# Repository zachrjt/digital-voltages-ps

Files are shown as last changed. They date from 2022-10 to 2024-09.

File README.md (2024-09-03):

# **Dual Fixed-Voltage Power Supply with V,I Readout**
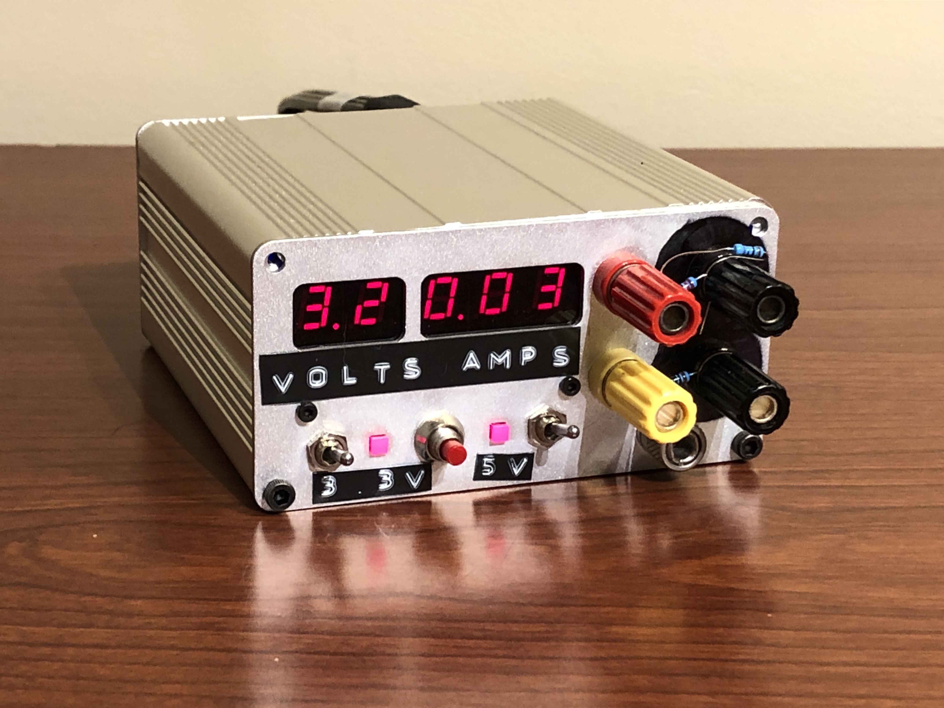
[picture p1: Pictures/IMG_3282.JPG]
Complete PS

## Background
The motivation behind this project was that in the past I have come across a need for a portable fixed-voltage 3.3V and 5V supplies. Specifically, I needed a supply that didn’t require me to set up a variable lab power supply while also being portable and rugged so that I could take it on the go.
Why did it end up taking on this *”polished”* look? I was looking to gain more SMD soldering experience and further my experience in PCB layout and schematic documentation. So, I approached this project in a more methodical, thorough-engineering manner than what I do typically for other personal projects of mine.
## Design and Construction
The main and display PCBs were captured and routed in KiCad, while the back and front enclosure panels were designed in Fusion 360. The code was, and is, written using the Arduino IDE and framework thanks only to the existence of the megaTinyCore library for 2-series attiny chips.
## Result
As seen in the picture above, the resulting power supply is certainly an *aesthetic*, but it is functional which is the most important thing. It took two PCB revisions of the main board because of wrong footprints for two resistors, and ~1 month of daily effort. There were many hours spent at my bench with an oscilloscope debugging my own oversights in the first PCB revision but I enjoyed every minute. The approach I took paid off since I've gained a lot of knowledge and experience where I wanted to, and the result is something I'm proud to share.

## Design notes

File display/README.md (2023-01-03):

# Display Board Schematic, PCB, and Documentation

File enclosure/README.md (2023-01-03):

# Back and Front Enclosure Panel CAD Files and Drawings

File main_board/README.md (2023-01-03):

# Main Board Schematic, PCB, and Documentation

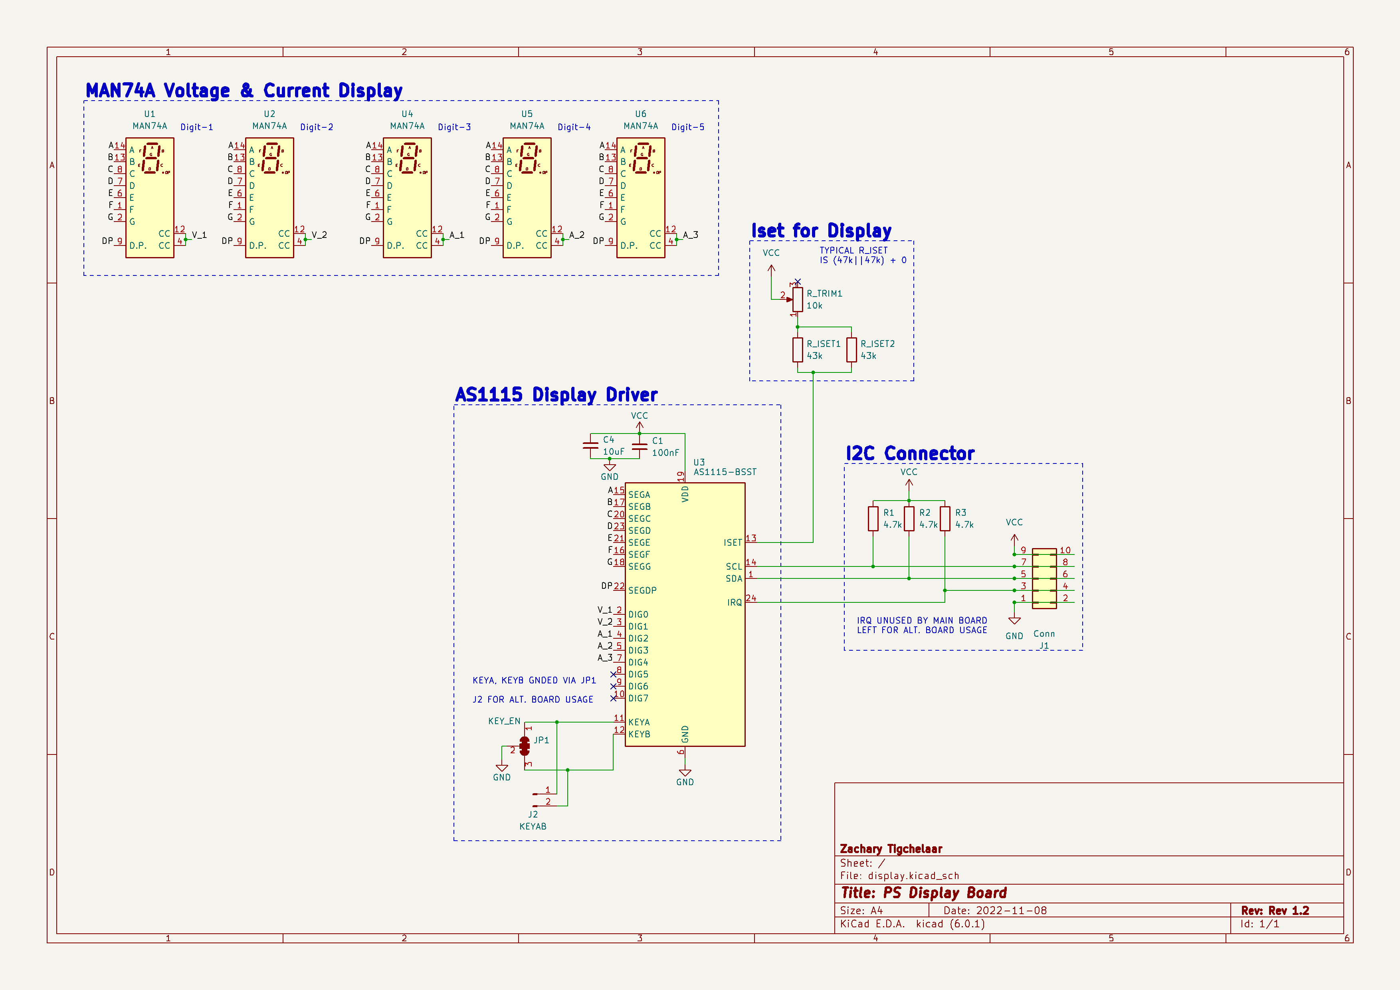
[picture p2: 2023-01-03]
display/display_board_schematic.png

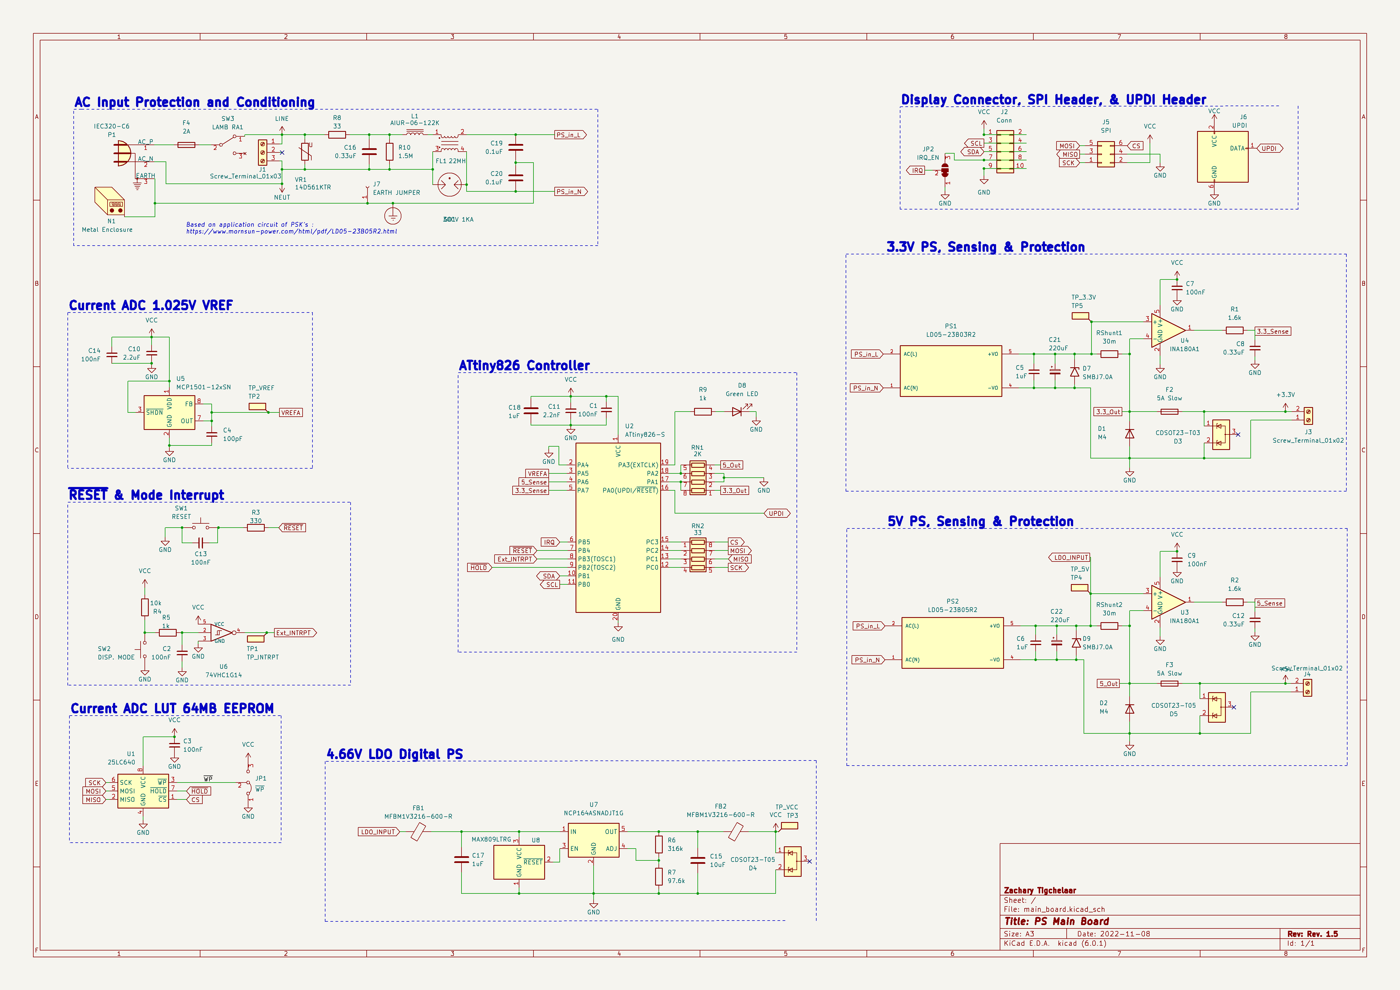
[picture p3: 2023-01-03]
main_board/main_board_schematic.png

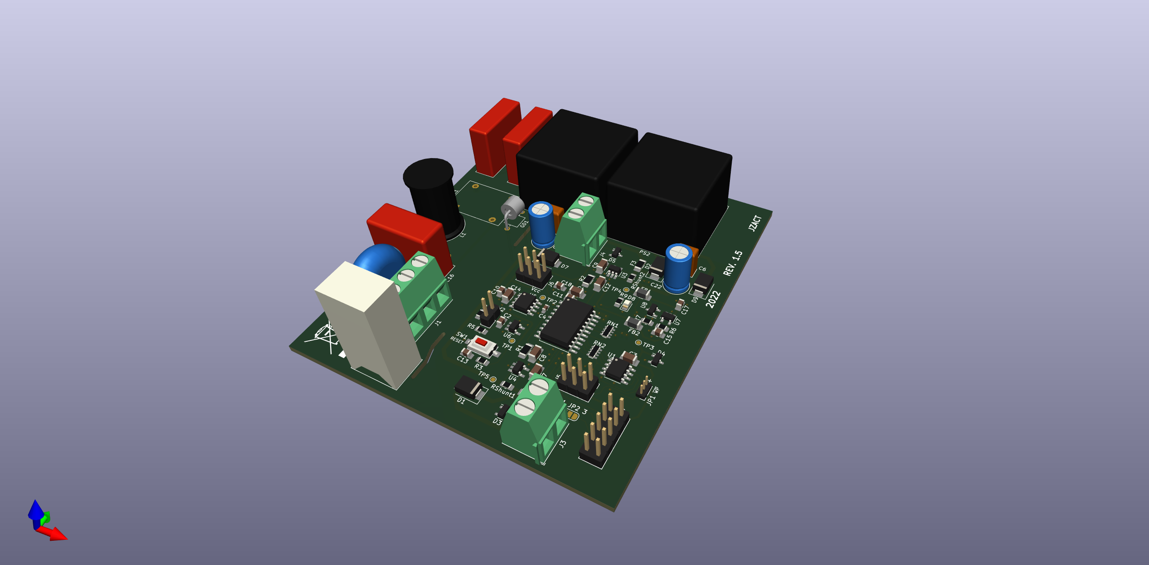
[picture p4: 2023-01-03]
main_board/main_board_iso_view.png

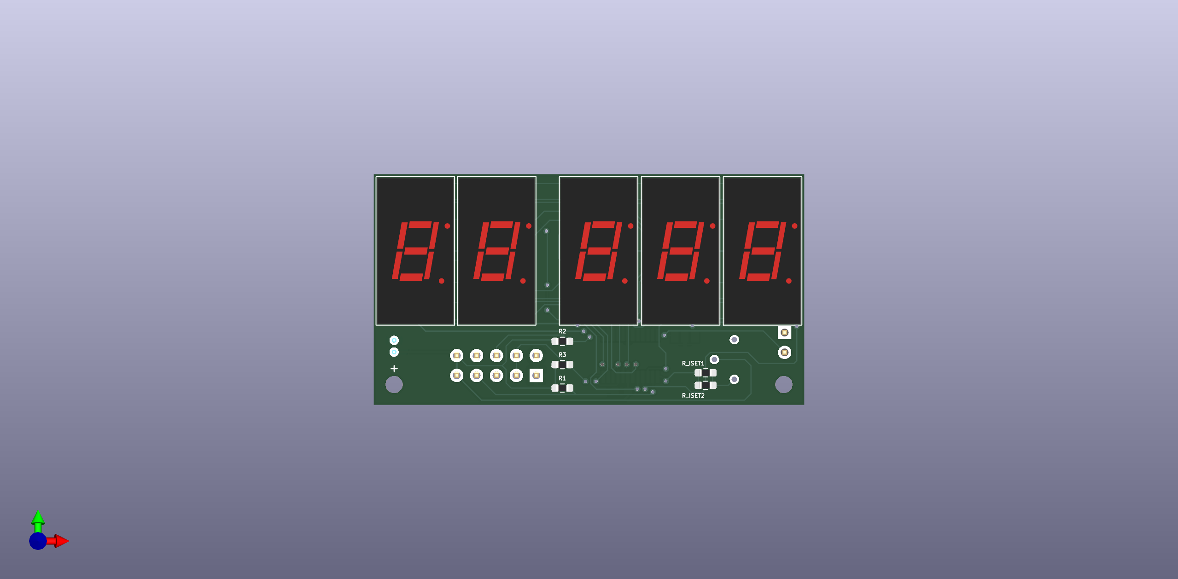
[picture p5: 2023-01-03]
display/display_top_view.png

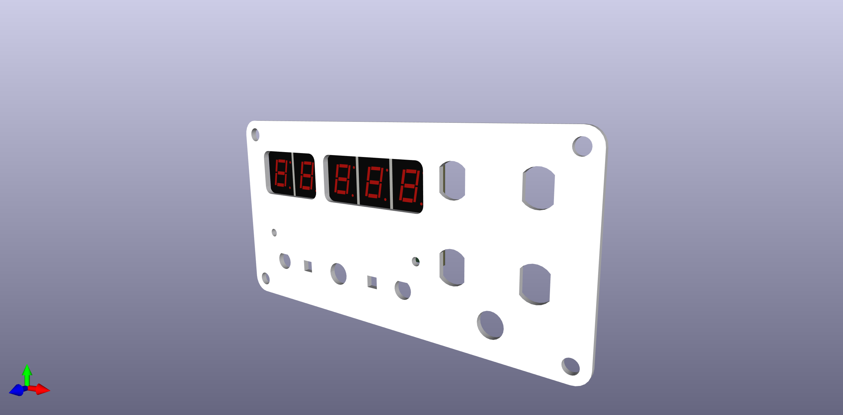
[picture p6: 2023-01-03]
display/display_iso_view.png

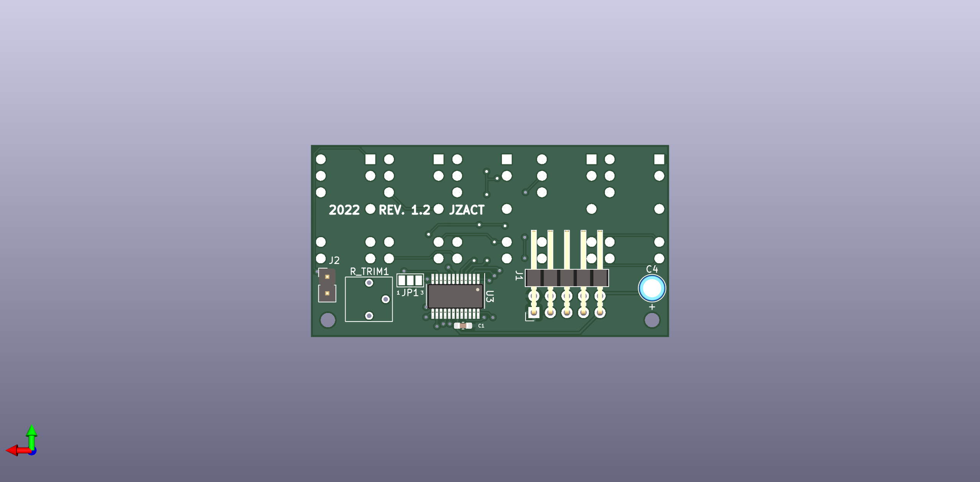
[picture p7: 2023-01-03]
display/display_bottom_view.png

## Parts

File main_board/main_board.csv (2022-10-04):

Source: | C:\git\ps\main_board\main_board.kicad_sch
Date: | 2022-07-29 15:25
Tool: | Eeschema (6.0.1)
Generator: | C:\Program Files\KiCad\6.0\bin\scripting\plugins/bom_csv_grouped_by_value_with_fp.py
Component Count: | 66
Ref | Qnty | Value | Cmp name | Description | Vendor
C1, C3, C7, C9, C14, | 5 | 100nF | C_Small | Unpolarized capacitor, small symbol
C2, | 1 | 0.1uF | C | Unpolarized capacitor
C4, | 1 | 100pF | C_Small | Unpolarized capacitor, small symbol
C5, C6, | 2 | 220uF | C_Small | Unpolarized capacitor, small symbol
C8, C12, | 2 | C_Small | C_Small | Unpolarized capacitor, small symbol
C10, | 1 | 2.2uF | C_Small | Unpolarized capacitor, small symbol
C11, | 1 | 2.2nF | C_Small | Unpolarized capacitor, small symbol
C13, C16, | 2 | 100nF | C_Small | Unpolarized capacitor, small symbol
C15, | 1 | 10uF | C | Unpolarized capacitor
C17, | 1 | 1uF | C | Unpolarized capacitor
D1, D2, | 2 | 1N4002 | 1N4002 | 100V 1A General Purpose Rectifier Diode, DO-41
D3, D4, D5, | 3 | CDSOT23-TXXC | CDSOT23-TXXC | TVS Diode Array, 5V, 3V, Bi-directional SOT-23 package, ESD
D6, | 1 | M3 | D | Diode
D8, | 1 | LED | LED | Light emitting diode
F2, F3, | 2 | 1.25A | Fuse | Fuse
FB1, FB2, | 2 | MFBM1V3216-600-R | FerriteBead | Ferrite bead
FL1, | 1 | Choke_Schaffner_RN114-1.2-02-10M | Choke_Schaffner_RN114-1.2-02-10M | Common mode choke, 1.2A, 300VAC, 10mH, 1.3 ohm, RN-114
J1, | 1 | Screw_Terminal_01x03 | Screw_Terminal_01x03 | Generic screw terminal, single row, 01x03, script generated (kicad-library-utils/schlib/autogen/connector/)
J2, | 1 | UPDI | AVR-UPDI-6 | Atmel 6-pin UPDI connector
J3, J4, | 2 | Screw_Terminal_01x02 | Screw_Terminal_01x02 | Generic screw terminal, single row, 01x02, script generated (kicad-library-utils/schlib/autogen/connector/)
J5, | 1 | Conn | Conn_02x05_Odd_Even | Generic connector, double row, 02x05, odd/even pin numbering scheme (row 1 odd numbers, row 2 even numbers), script generated (kicad-library-utils/schlib/autogen/connector/)
J6, | 1 | SPI | Conn_02x03_Odd_Even | Generic connector, double row, 02x03, odd/even pin numbering scheme (row 1 odd numbers, row 2 even numbers), script generated (kicad-library-utils/schlib/autogen/connector/)
JP1, | 1 | ~{WP} | Jumper_3_Bridged12 | Jumper, 3-pole, pins 1+2 closed/bridged
JP2, | 1 | IRQ ENABLE | SolderJumper_2_Open | Solder Jumper, 2-pole, open
PS1, | 1 | HLK-PM03 | HLK-PM03 | Compact AC/DC board mount power module 3W 3.3V
PS2, | 1 | HLK-5M05 | HLK-5M05 | Compact AC/DC board mount power module 5W 5V
R1, R2, | 2 | R | R | Resistor
R3, R9, | 2 | 330 | R | Resistor
R4, | 1 | 10k | R | Resistor
R6, | 1 | 324k | R | Resistor
R7, | 1 | 97.6k | R | Resistor
RN1, | 1 | 2K | R_Pack04 | 4 resistor network, parallel topology
RN2, | 1 | 560 | R_Pack04 | 4 resistor network, parallel topology
RShunt1, RShunt2, | 2 | 30m | R | Resistor
SW1, | 1 | RESET | SW_Push | Push button switch, generic, two pins
SW2, | 1 | DISP. MODE | SW_Push | Push button switch, generic, two pins
TP1, | 1 | TP_INTRPT | TestPoint_Flag | test point (alternative flag-style design)
TP2, | 1 | TP_VREF | TestPoint_Flag | test point (alternative flag-style design)
TP3, | 1 | TP_VCC | TestPoint_Flag | test point (alternative flag-style design)
TP4, | 1 | TP_5V | TestPoint_Flag | test point (alternative flag-style design)
TP5, | 1 | TP_3.3V | TestPoint_Flag | test point (alternative flag-style design)
U1, | 1 | 25LC640 | 25LC640 | SPI Serial EEPROM, DIP-8/SOIC-8/TSSOP-8
U2, | 1 | ATtiny826-S | ATtiny826-S | 20MHz, 8kB Flash, 1Kb SRAM, 128B EEPROM, debugWIRE, 20-SOIC
U3, U4, | 2 | INA180A1 | INA180A1 | Low- and High-Side Measurement Current Shunt Monitor, 26V, SOT-23-5
U5, | 1 | MCP1501-12xSN | MCP1501-12xSN | 1.25V, 0.1%, 20mA, Precision Voltage Reference, SOIC-8
U6, | 1 | 74VHC1G14 | 74VHC1G14 | Single Schmitt NOT Gate, Low-Voltage CMOS
U7, | 1 | NCP164ASNADJT1G | NCP164ASNADJT1G | 300mA Low-Dropout Linear Regulators, Adjustable output voltage, LDO with low noise and enable pin, TSOP-5
U8, | 1 | MAX809 | MAX809 | Power supply supervisor, Threshold 4.63V, SOT-23
VR1, | 1 | 10D561K | Varistor | Voltage dependent resistor

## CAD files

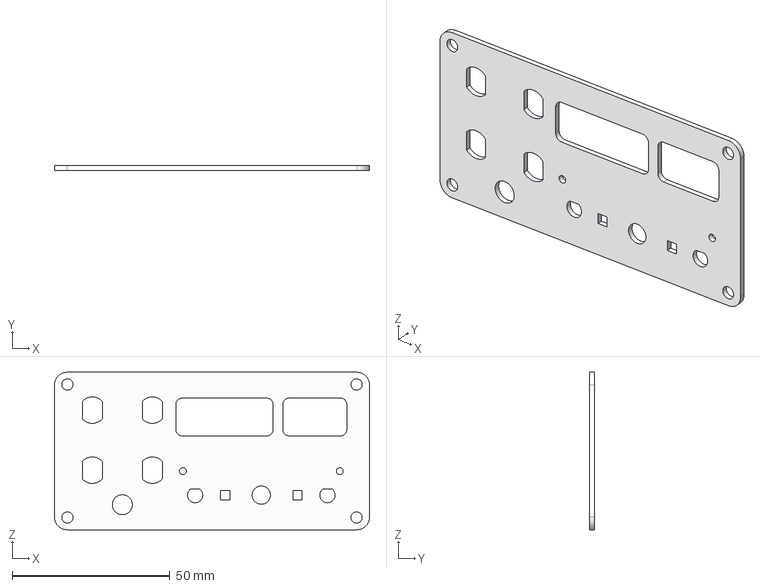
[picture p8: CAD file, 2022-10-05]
enclosure/front_face_plate v22.step
100.0 x 1.50 x 50.0 mm

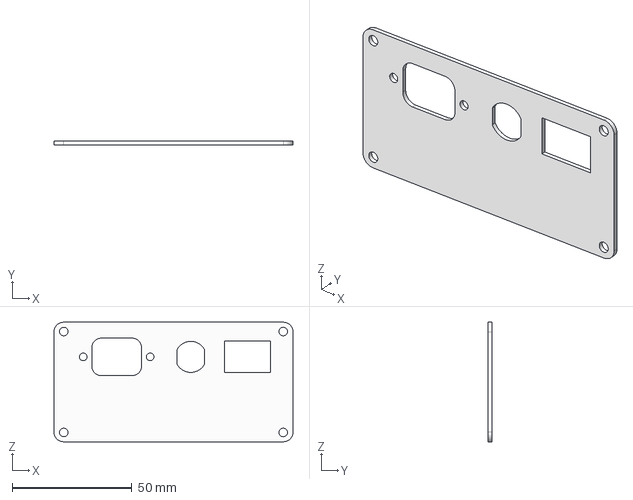
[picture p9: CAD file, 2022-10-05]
enclosure/back_face_plate v17.step
100.0 x 1.50 x 50.0 mm

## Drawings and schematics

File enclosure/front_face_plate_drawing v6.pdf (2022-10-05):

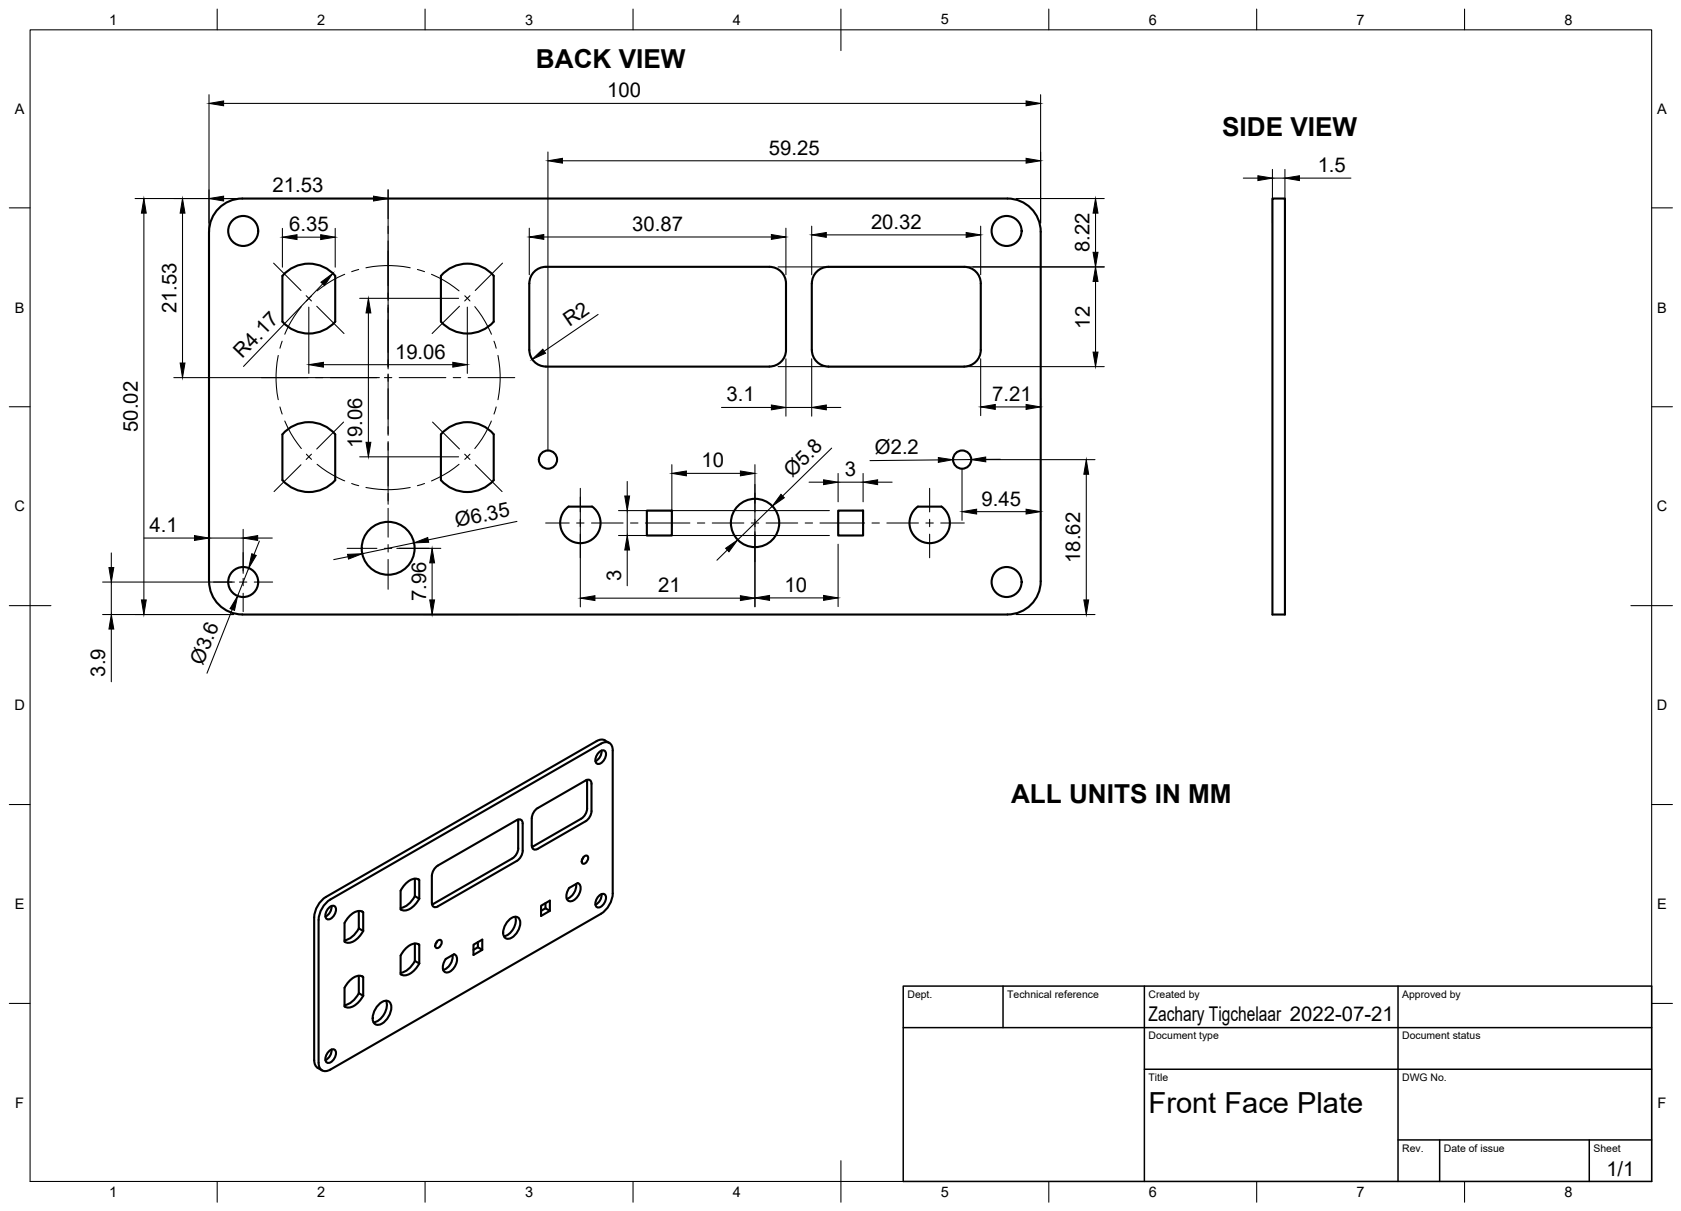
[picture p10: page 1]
Title; DWG No.; Rev.; Date of issue; Sheet; BACK VIEW; SIDE VIEW

ALL UNITS IN MM

Dept. | Technical reference | Created by Zachary Tigchelaar 2022-07-21 | Approved by

Document type | Document status

Front Face Plate

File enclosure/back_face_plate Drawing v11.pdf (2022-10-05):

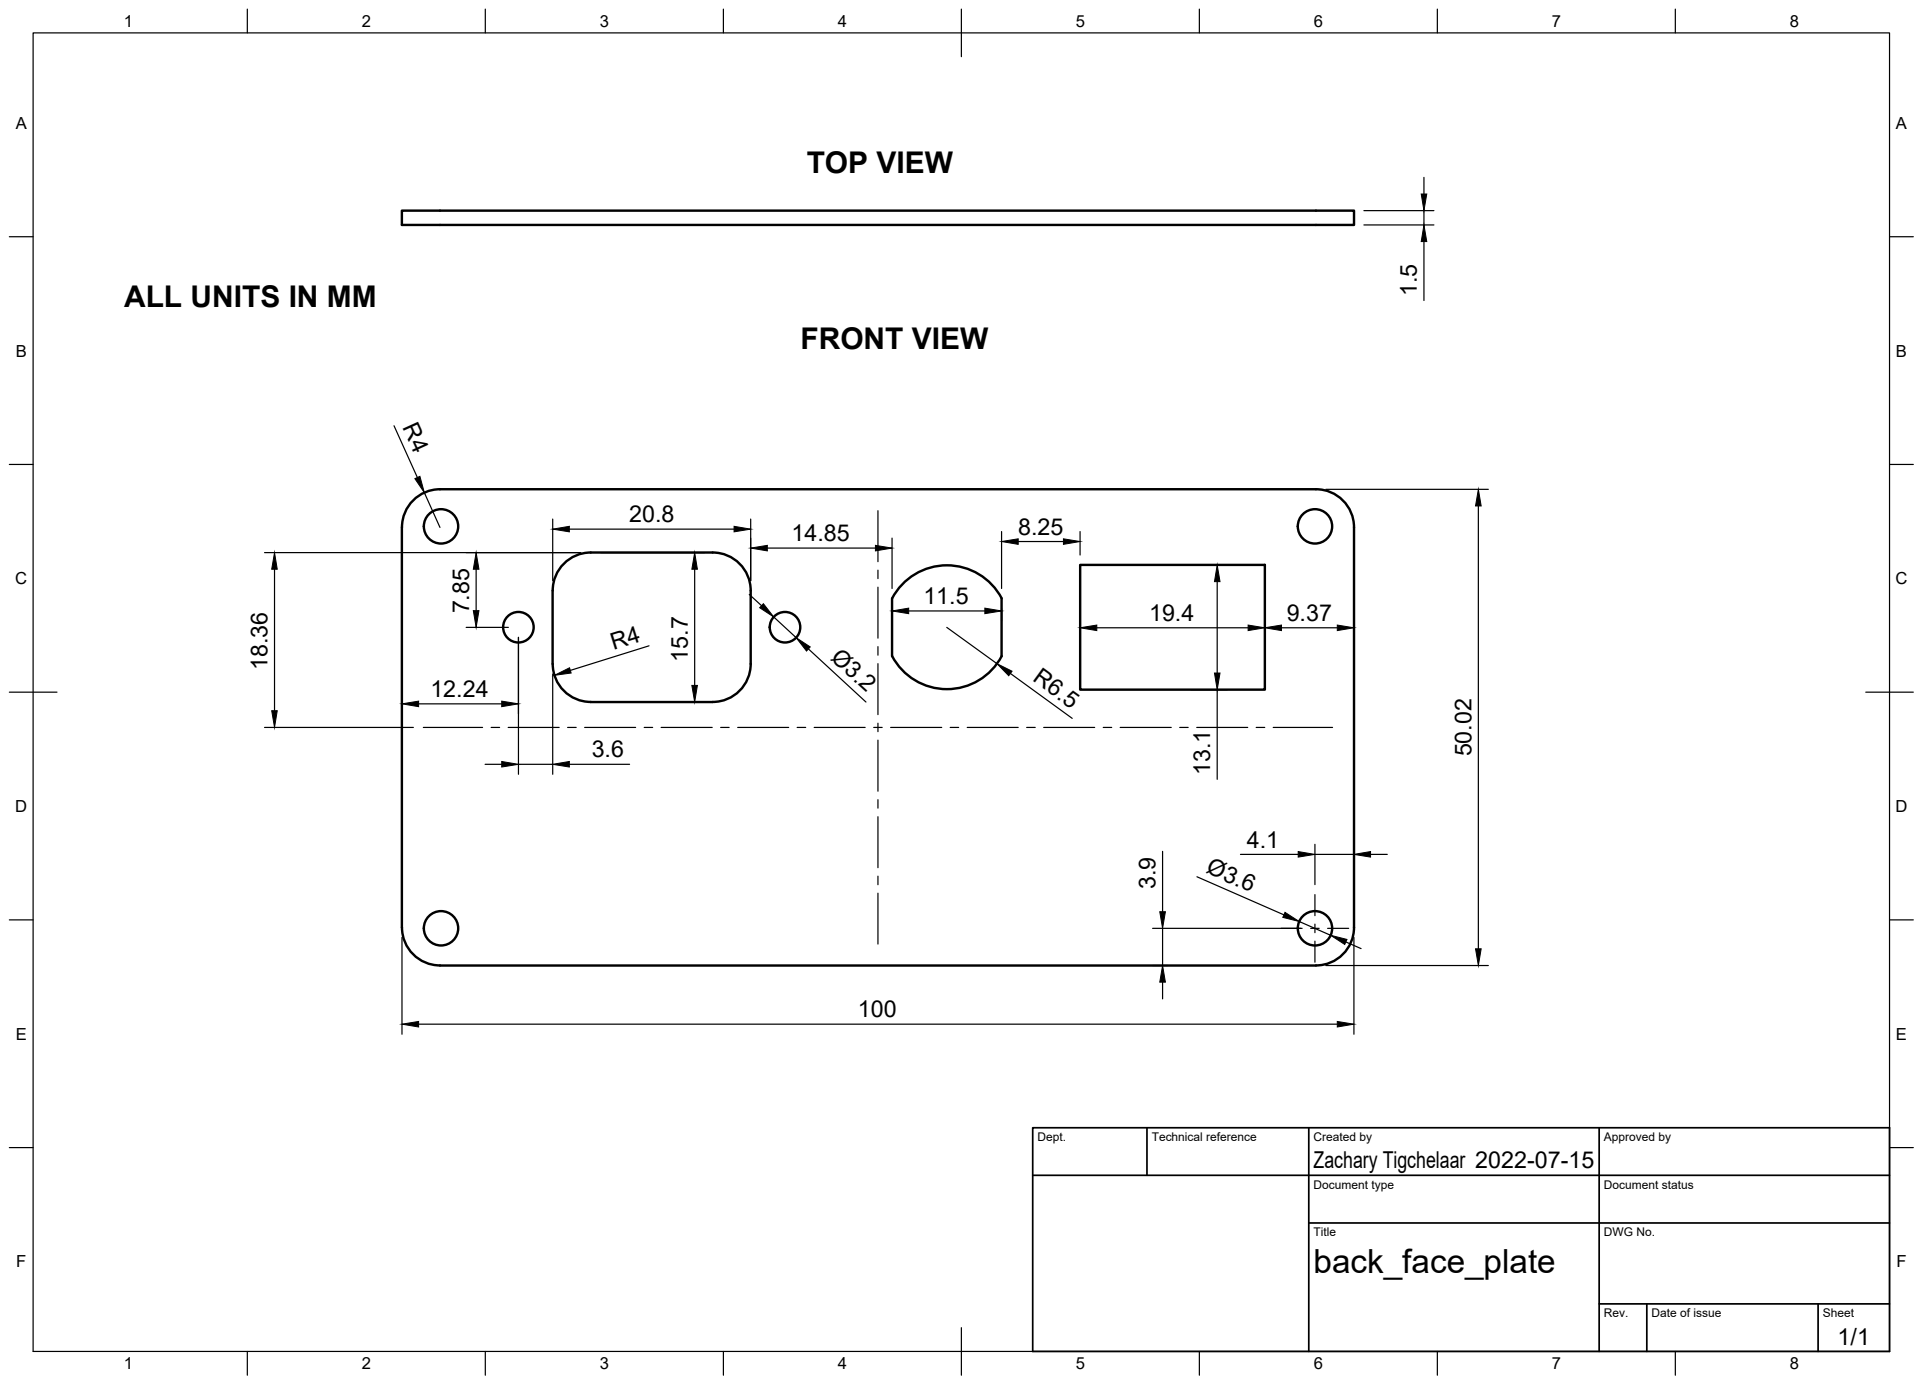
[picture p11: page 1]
Title; DWG No.; Rev.; Date of issue; Sheet; Zachary Tigchelaar 1.5; TOP VIEW; FRONT VIEW

ALL UNITS IN MM

Dept. | Technical reference | Created by 2022-07-15 | Approved by

Document type | Document status

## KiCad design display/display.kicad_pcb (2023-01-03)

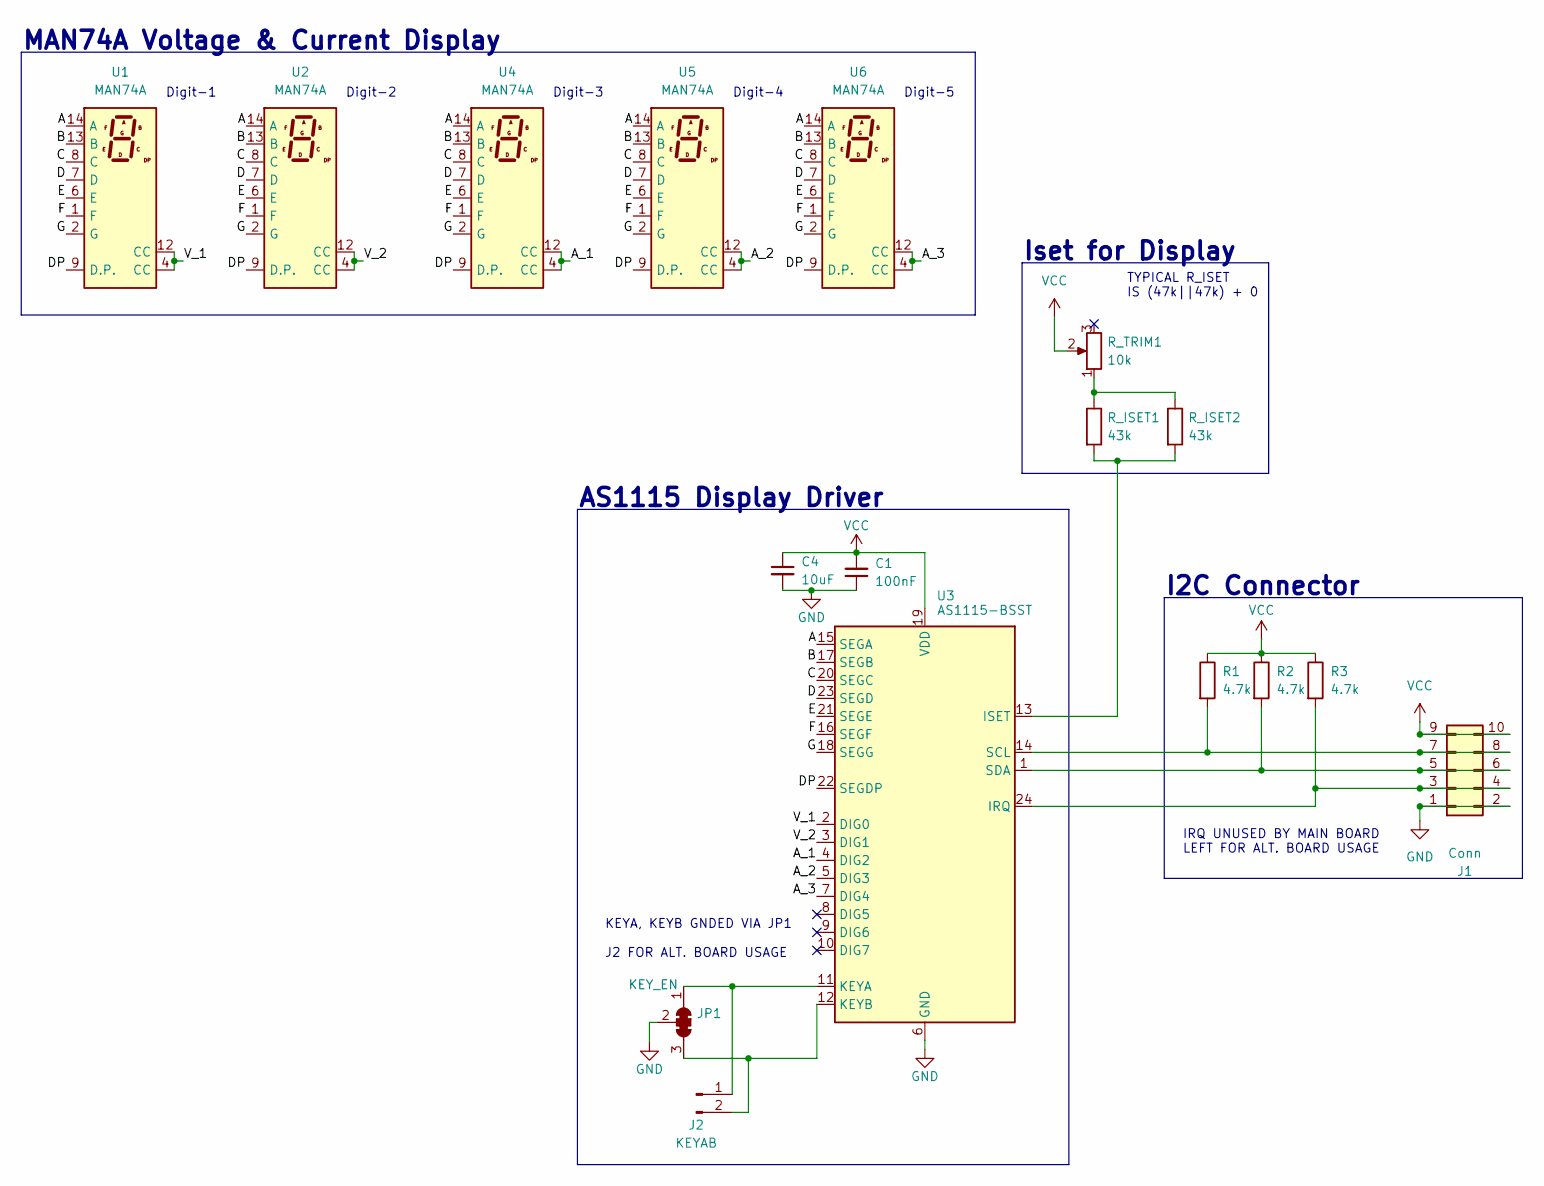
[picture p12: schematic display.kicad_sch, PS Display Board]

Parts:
C1: 100nF; C_0603_1608Metric_Pad1.08x0.95mm_HandSolder
C4: 10uF; C_Radial_D4.0mm_H5.0mm_P1.50mm
J1: Conn; PinHeader_2x05_P2.54mm_Horizontal
J2: KEYAB; PinHeader_1x02_P2.54mm_Vertical
JP1: KEY_EN; SolderJumper-3_P1.3mm_Open_Pad1.0x1.5mm_NumberLabels
R1, R2, R3: 4.7k; R_0603_1608Metric_Pad0.98x0.95mm_HandSolder
R_ISET1, R_ISET2: 43k; R_0603_1608Metric_Pad0.98x0.95mm_HandSolder
R_TRIM1: 10k; Potentiometer_Bourns_3362P_Vertical
U1, U2, U4, U5, U6: MAN74A
U3: AS1115-BSST; QSOP-24_3.9x8.7mm_P0.635mm

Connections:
/A: U1.14 (A), U2.14 (A), U3.15 (SEGA), U4.14 (A), U5.14 (A), U6.14 (A)
/A_1: U3.4 (DIG2), U4.4 (CC), U4.12 (CC)
/A_2: U3.5 (DIG3), U5.4 (CC), U5.12 (CC)
/A_3: U3.7 (DIG4), U6.4 (CC), U6.12 (CC)
/B: U1.13 (B), U2.13 (B), U3.17 (SEGB), U4.13 (B), U5.13 (B), U6.13 (B)
/C: U1.8 (C), U2.8 (C), U3.20 (SEGC), U4.8 (C), U5.8 (C), U6.8 (C)
/D: U1.7 (D), U2.7 (D), U3.23 (SEGD), U4.7 (D), U5.7 (D), U6.7 (D)
/DP: U1.9 (D.P.), U2.9 (D.P.), U3.22 (SEGDP), U4.9 (D.P.), U5.9 (D.P.), U6.9 (D.P.)
/E: U1.6 (E), U2.6 (E), U3.21 (SEGE), U4.6 (E), U5.6 (E), U6.6 (E)
/F: U1.1 (F), U2.1 (F), U3.16 (SEGF), U4.1 (F), U5.1 (F), U6.1 (F)
/G: U1.2 (G), U2.2 (G), U3.18 (SEGG), U4.2 (G), U5.2 (G), U6.2 (G)
/V_1: U1.4 (CC), U1.12 (CC), U3.2 (DIG0)
/V_2: U2.4 (CC), U2.12 (CC), U3.3 (DIG1)
GND: C1.1, C4.2, J1.1, J1.2, JP1.2 (C), U3.6 (GND)
unnamed: J2.1, JP1.1 (A), U3.11 (KEYA)
unnamed: J2.2, JP1.3 (B), U3.12 (KEYB)
unnamed: J1.7, J1.8, R1.2, U3.14 (SCL)
unnamed: J1.5, J1.6, R2.2, U3.1 (SDA)
unnamed: J1.3, J1.4, R3.2, U3.24 (IRQ)
unnamed: R_ISET1.1, R_ISET2.1, R_TRIM1.1
unnamed: R_ISET1.2, R_ISET2.2, U3.13 (ISET)
VCC: C1.2, C4.1, J1.9, J1.10, R1.1, R2.1, R3.1, R_TRIM1.2, U3.19 (VDD)

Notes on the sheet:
TYPICAL R_ISET IS (47k||47k) + 0
I2C Connector
Digit-3
AS1115 Display Driver
KEYA, KEYB GNDED VIA JP1 J2 FOR ALT. BOARD USAGE
Digit-4
Iset for Display
Digit-5
Digit-2
MAN74A Voltage & Current Display
Digit-1
IRQ UNUSED BY MAIN BOARD LEFT FOR ALT. BOARD USAGE

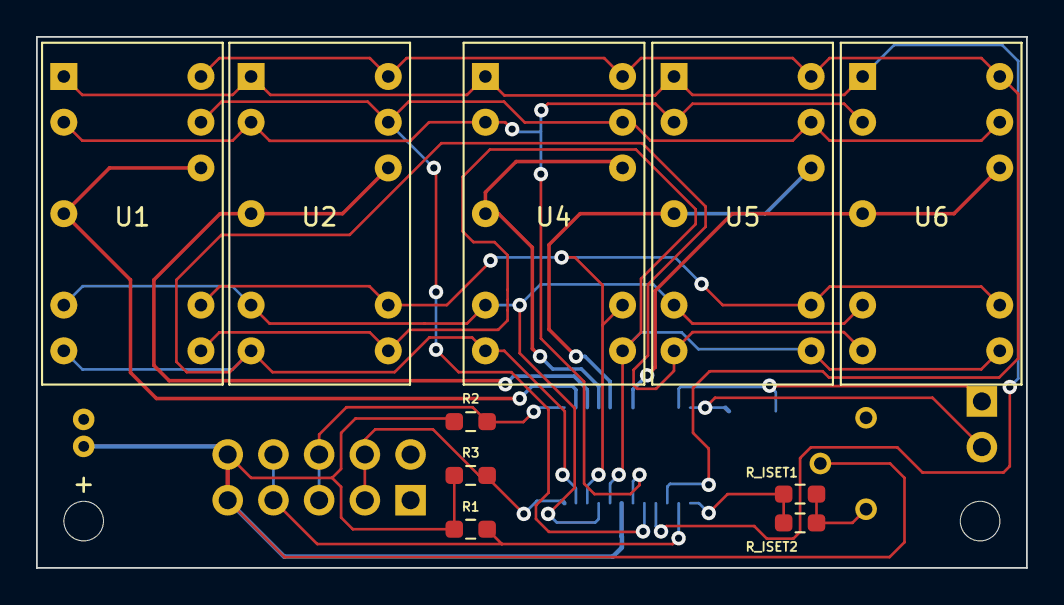
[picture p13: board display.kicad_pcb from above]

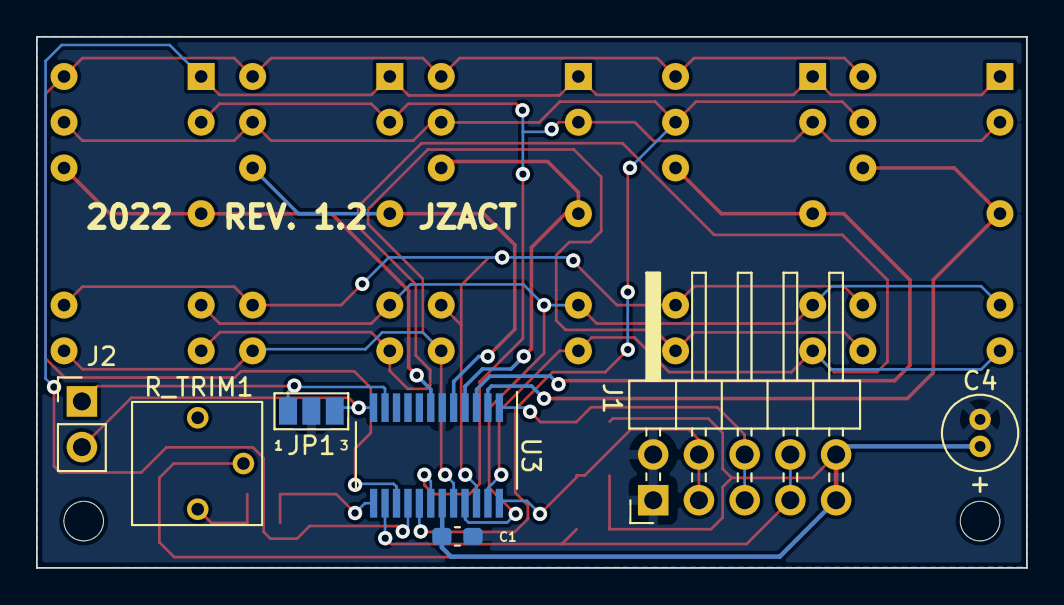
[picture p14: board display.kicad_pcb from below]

Board: 2 copper layers, 55.0 x 29.5 mm, 20 parts (7 on the bottom side), 22 nets.

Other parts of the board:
M1, M3: MountingHole_2.2mm_M2
M4: display_cutout

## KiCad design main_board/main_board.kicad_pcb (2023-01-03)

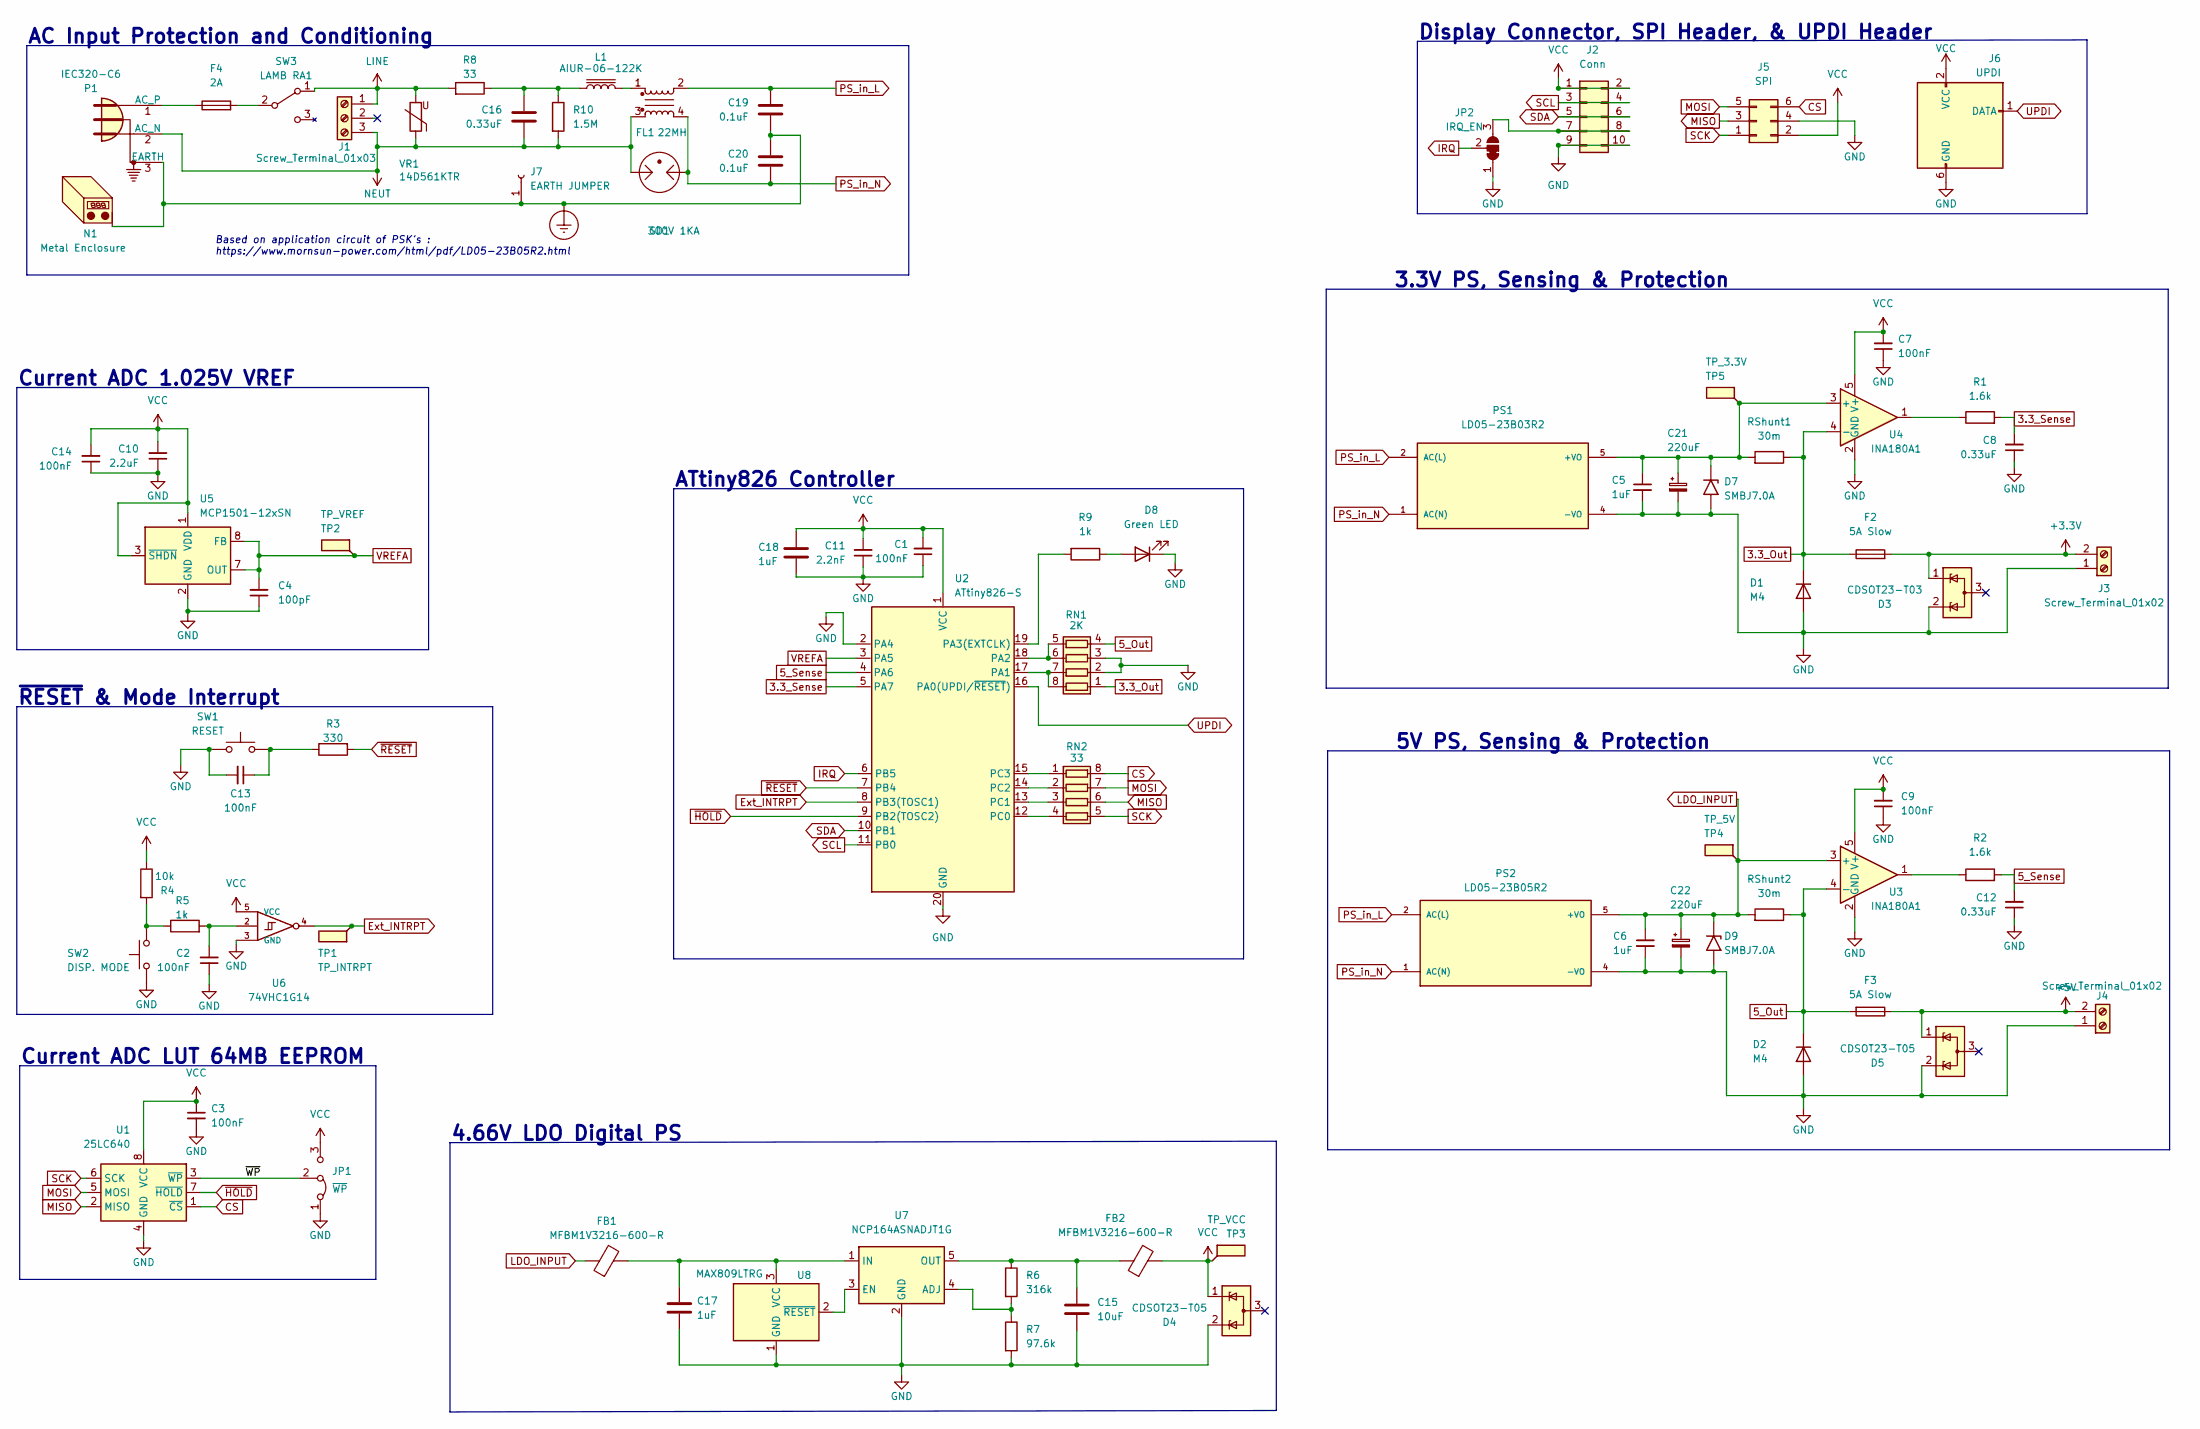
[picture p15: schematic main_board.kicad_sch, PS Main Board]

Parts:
C1, C3, C7, C9, C14: 100nF; C_1206_3216Metric_Pad1.33x1.80mm_HandSolder
C2, C13: 100nF; C_0805_2012Metric_Pad1.18x1.45mm_HandSolder
C4: 100pF; C_0603_1608Metric_Pad1.08x0.95mm_HandSolder
C5, C6: 1uF; C320C105K5R5TA
C8, C12: 0.33uF; C_1206_3216Metric_Pad1.33x1.80mm_HandSolder
C10: 2.2uF; C_0805_2012Metric_Pad1.18x1.45mm_HandSolder
C11: 2.2nF; C_0805_2012Metric_Pad1.18x1.45mm_HandSolder
C15: 10uF; C_0805_2012Metric_Pad1.18x1.45mm_HandSolder
C16: 0.33uF; C_Rect_L18.0mm_W8.0mm_P15.00mm_FKS3_FKP3
C17, C18: 1uF; C_0805_2012Metric_Pad1.18x1.45mm_HandSolder
C19, C20: 0.1uF; C_Rect_L18.0mm_W6.0mm_P15.00mm_FKS3_FKP3
C21, C22: 220uF; C_Radial_D6.3mm_H11.0mm_P2.50mm
D1, D2: M4; D_SMB
D3: CDSOT23-T03; SOT-23
D4, D5: CDSOT23-T05; SOT-23
D7, D9: SMBJ7.0A; D_SMB
D8: Green LED; LED_0805_2012Metric_Pad1.15x1.40mm_HandSolder
F2, F3: 5A Slow; Fuse_1206_3216Metric_Pad1.42x1.75mm_HandSolder
F4: 2A
FB1, FB2: MFBM1V3216-600-R; L_1206_3216Metric_Pad1.42x1.75mm_HandSolder
FL1: 22MH; Choke_Schaffner_RN218-04-12.5x18.0mm
GD1: 300V 1KA; 2035-GDT
J1: Screw_Terminal_01x03; TerminalBlock_Phoenix_MKDS-1,5-3-5.08_1x03_P5.08mm_Horizont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
J2: Conn; PinHeader_2x05_P2.54mm_Vertical
J3, J4: Screw_Terminal_01x02; TerminalBlock_Phoenix_MKDS-1,5-2-5.08_1x02_P5.08mm_Horizont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
J5: SPI; PinHeader_2x03_P2.54mm_Vertical
J6: UPDI; PinHeader_2x03_P2.54mm_Vertical
J7: EARTH JUMPER; PinHeader_1x01_P2.54mm_Vertical
JP1: ~{WP}; PinHeader_1x03_P1.27mm_Vertical
JP2: IRQ_EN; SolderJumper-3_P1.3mm_Open_RoundedPad1.0x1.5mm_NumberLabels
L1: AIUR-06-122K; AIUR-06
N1: Metal Enclosure
P1: IEC320-C6
PS1: LD05-23B03R2; CONV_LD05-23B03R2; PARTREV 2020.06.30-A/2
PS2: LD05-23B05R2; CONV_LD05-23B05R2; PARTREV 2020.06.30-A/2
R1, R2: 1.6k; R_1206_3216Metric_Pad1.30x1.75mm_HandSolder
R3: 330; R_0805_2012Metric_Pad1.20x1.40mm_HandSolder
R4: 10k; R_0805_2012Metric_Pad1.20x1.40mm_HandSolder
R5, R9: 1k; R_0805_2012Metric_Pad1.20x1.40mm_HandSolder
R6: 316k; R_0805_2012Metric_Pad1.20x1.40mm_HandSolder
R7: 97.6k; R_0805_2012Metric_Pad1.20x1.40mm_HandSolder
R8: 33; R_Radial_Power_L13.0mm_W9.0mm_P5.00mm
R10: 1.5M; R_Axial_DIN0207_L6.3mm_D2.5mm_P10.16mm_Horizontal
RN1: 2K; R_Array_Convex_4x0603
RN2: 33; R_Array_Convex_4x0603
RShunt1, RShunt2: 30m; R_0805_2012Metric_Pad1.20x1.40mm_HandSolder
SW1: RESET; SW_SPST_CK_RS282G05A3
SW2: DISP. MODE; PinHeader_1x02_P2.54mm_Vertical
SW3: LAMB RA1
TP1: TP_INTRPT; TestPoint_Pad_D1.0mm
TP2: TP_VREF; TestPoint_Pad_D1.0mm
TP3: TP_VCC; TestPoint_Pad_D1.0mm
TP4: TP_5V; TestPoint_Pad_D1.0mm
TP5: TP_3.3V; TestPoint_Pad_D1.0mm
U1: 25LC640; SOIC-8_3.9x4.9mm_P1.27mm
U2: ATtiny826-S; SOIC-20W_7.5x12.8mm_P1.27mm
U3, U4: INA180A1; SOT-23-5_HandSoldering
U5: MCP1501-12xSN; SOIC-8_3.9x4.9mm_P1.27mm
U6: 74VHC1G14; SOT-23-5_HandSoldering
U7: NCP164ASNADJT1G; TSOP-5
U8: MAX809LTRG; SOT-23
VR1: 14D561KTR; RV_Disc_D16.5mm_W6.7mm_P7.5mm

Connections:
3.3_Out: D1.1 (K), F2.1, RN1.1 (R1.1), RShunt1.1, U4.4 (-)
3.3_Sense: C8.2, R1.2, U2.5 (PA7)
5_Out: D2.1 (K), F3.2, RN1.4 (R4.1), RShunt2.1, U3.4 (-)
5_Sense: C12.2, R2.2, U2.4 (PA6)
+3V3: D3.1 (K), F2.2, J3.2
+5V: D5.1 (K), F3.1, J4.2
/~WP: JP1.2 (C), U1.3 (~WP)
CS: J5.6, RN2.8 (R1.2), U1.1 (~CS)
Earth_Protective: C19.1, C20.2, J7.1, N1.1, P1.3 (EARTH)
Ext_INTRPT: TP1.1, U2.8 (PB3(TOSC1)), U6.4
GND: C1.1, C2.1, C3.2, C4.1, C5.2, C6.2, C7.1, C8.1, C9.1, C10.1, C11.1, C12.1, C13.2, C14.1, C15.2, C17.2, C18.2, C21.2, C22.2, D1.2 (A), D2.2 (A), D3.2 (K), D4.2 (K), D5.2 (K), D7.2 (A2), D8.1 (K), D9.2 (A2), J2.9, J2.10, J3.1, J4.1, J5.4, J6.6 (GND), JP1.1 (A), JP2.1 (A), PS1.4 (-VO), PS2.4 (-VO), R7.2, RN1.2 (R2.1), RN1.3 (R3.1), SW1.1, SW2.1, U1.4 (GND), U2.2 (PA4), U2.20 (GND), U3.2 (GND), U4.2 (GND), U5.2 (GND), U5.4 (GND), U5.5 (GND), U5.6 (GND), U6.3 (GND), U7.2 (GND), U8.1 (GND)
IRQ: JP2.2 (C), U2.6 (PB5)
LDO_INPUT: C6.1, C22.1, D9.1 (A1), FB1.1, PS2.5 (+VO), RShunt2.2, TP4.1, U3.3 (+)
LINE: J1.1, R8.2, SW3.1 (A), VR1.2
MISO: J5.3, RN2.6 (R3.2), U1.2 (MISO)
MOSI: J5.5, RN2.7 (R2.2), U1.5 (MOSI)
NEUT: C16.1, FL1.3, GD1.2, J1.3, P1.2 (AC_N), R10.2, VR1.1
unnamed: C2.2, R5.2, U6.2
unnamed: C15.1, FB2.1, R6.1, U7.5 (OUT)
unnamed: C16.2, L1.1, R8.1, R10.1
unnamed: C17.1, FB1.2, U7.1 (IN), U8.3 (VCC)
unnamed: C5.1, C21.1, D7.1 (A1), PS1.5 (+VO), RShunt1.2, TP5.1, U4.3 (+)
unnamed: D8.2 (A), R9.1
unnamed: F4.1, P1.1 (AC_P)
unnamed: F4.2, SW3.2 (B)
unnamed: FL1.1, L1.2
unnamed: J2.7, J2.8, JP2.3 (B)
unnamed: R1.1, U4.1
unnamed: R2.1, U3.1
unnamed: C13.1, R3.1, SW1.2
unnamed: R4.2, R5.1, SW2.2
unnamed: R6.2, R7.1, U7.4 (ADJ)
unnamed: R9.2, U2.19 (PA3(EXTCLK))
unnamed: RN1.5 (R4.2), RN1.6 (R3.2), U2.18 (PA2)
unnamed: RN1.7 (R2.2), RN1.8 (R1.2), U2.17 (PA1)
unnamed: RN2.1 (R1.1), U2.15 (PC3)
unnamed: RN2.2 (R2.1), U2.14 (PC2)
unnamed: RN2.3 (R3.1), U2.13 (PC1)
unnamed: RN2.4 (R4.1), U2.12 (PC0)
unnamed: U7.3 (EN), U8.2 (~RESET)
PS_in_L: C19.2, FL1.2, PS1.2 (AC(L)), PS2.2 (AC(L))
PS_in_N: C20.1, FL1.4, GD1.1, PS1.1 (AC(N)), PS2.1 (AC(N))
SCK: J5.1, RN2.5 (R4.2), U1.6 (SCK)
SCL: J2.3, J2.4, U2.11 (PB0)
SDA: J2.5, J2.6, U2.10 (PB1)
UPDI: J6.1 (DATA), U2.16 (PA0(UPDI/~RESET))
VCC: C1.2, C3.1, C7.2, C9.2, C10.2, C11.2, C14.2, C18.1, D4.1 (K), FB2.2, J2.1, J2.2, J5.2, J6.2 (VCC), JP1.3 (B), R4.1, TP3.1, U1.8 (VCC), U2.1 (VCC), U3.5 (V+), U4.5 (V+), U5.1 (VDD), U5.3 (~SHDN), U6.5 (VCC)
VREFA: C4.2, TP2.1, U2.3 (PA5), U5.7 (OUT), U5.8 (FB)
~HOLD: U1.7 (~HOLD), U2.9 (PB2(TOSC2))
~RESET: R3.2, U2.7 (PB4)

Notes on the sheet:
Display Connector, SPI Header, & UPDI Header
4.66V LDO Digital PS
~{RESET} & Mode Interrupt
Current ADC LUT 64MB EEPROM
Current ADC 1.025V VREF
AC Input Protection and Conditioning
5V PS, Sensing & Protection
Based on application circuit of PSK's : https://www.mornsun-power.com/html/pdf/LD05-23B05R2.html
3.3V PS, Sensing & Protection
ATtiny826 Controller

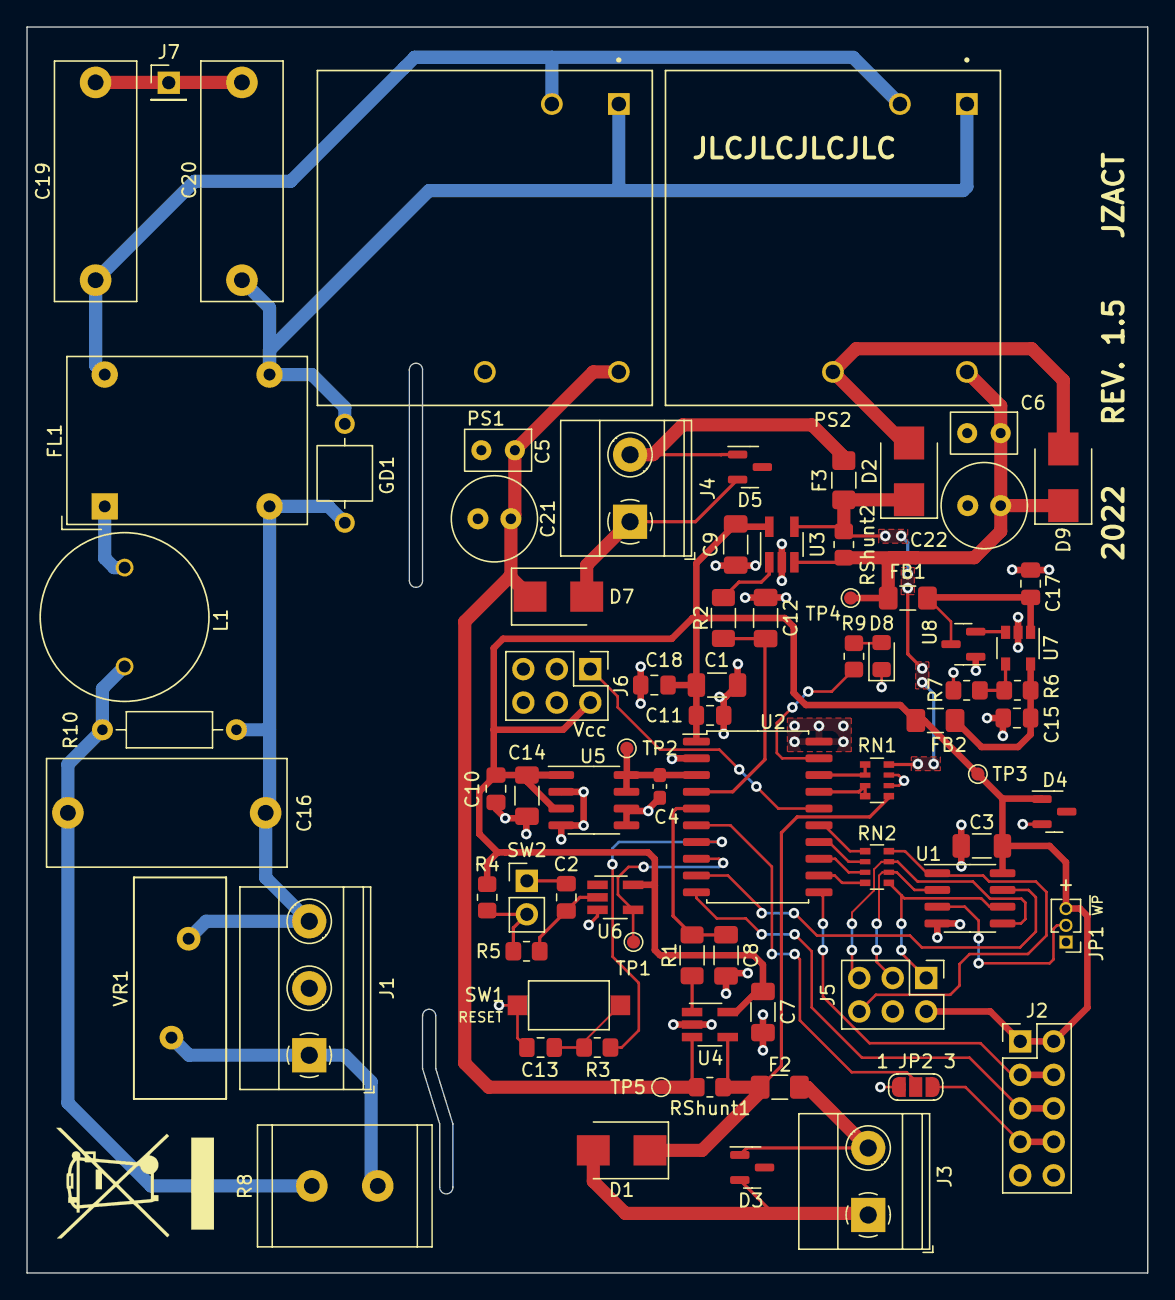
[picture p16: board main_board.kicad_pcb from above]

Board: 2 copper layers, 85.0 x 94.5 mm, 78 parts (0 on the bottom side), 48 nets.

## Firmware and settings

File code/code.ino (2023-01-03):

#include "main.h"

/*
 * (TODO)
 *  -Add ERROR checking indication via LED
 *    (https://github.com/SpenceKonde/megaTinyCore)
 *  -Improve the mode-switching button.
*/

//global constants

//global variables
bool value_state = false; //False=5V, True=3.3V

//Variables below are used in accumulated ADC-sample-to-BCD display conversion
float voltage = 0;
float current = 0;
String disp_volt = "";
String disp_amp = "";

uint8_t display_data[5] = {0,0,0,0,0};  // Stores the digit-values of the display

void setup()
{
  CLKCTRL.MCLKCTRLB = 0x00; // disable clock prescaling
  //Serial.pins(PIN_PC2 ,PIN_PC1); //hardware mod required for host uart-rx
  
  pinMode(CHIP_SELECT, OUTPUT);
  pinMode(LED_PIN, OUTPUT);
  pinMode(MODE_PIN, INPUT);
  digitalWrite(CHIP_SELECT, HIGH);
  digitalWrite(LED_PIN, HIGH);
  
  DisplayInit();  //Initializes the display driver over I2C
}


void loop()
{
  Current_ADCReading();
  Voltage_ADCReading();
  
  DispUpdate(0x05, &display_data[0]);

  //Check if mode-button is being pressed (not the most efficent debouncing)
  if(digitalRead(MODE_PIN) == HIGH)
  {
    delay(60);
    if(digitalRead(MODE_PIN) == HIGH)
    {
      value_state = !(value_state);
      voltage = 0;
      current = 0;
    }
  }
}

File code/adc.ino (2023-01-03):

#include "adc.h"
/*
 * (TODO)
 *  -Transistion ADC code over to the megaTinycore non-standard functions for 
 *  hardware based 8 & 12bit burst sampling.
 *    (https://github.com/SpenceKonde/megaTinyCore/blob/master/megaavr/extras/Ref_Analog.md)
 *  -Create dibble-dabble or lut table conversion of ADC samples (depends on transistioned ADC code).
 *    Current adc sample conversion is HIGHLY inefficient (int32->string->int8).
*/
 
void Voltage_ADCReading()
{
  int temp_adc_value = 0x00;
  uint8_t input_pin = (value_state) ? PIN_PA1 : PIN_PA2; //False(default) = 3.3V, True = 5V
  
  analogReference(INTERNAL4V096);
  analogReadResolution(10);
  analogSampleDuration(10);
  delay(1);
  
  for (int i = 0x00; i < 0xFF; i++)
  {
    temp_adc_value = analogRead(input_pin);
    voltage = voltage + (temp_adc_value * (4.096/1024));
  }
  voltage = voltage/(128);
  
  disp_volt = String(voltage, 3);
  display_data[0] = (uint8_t)(disp_volt[0]) - 0x30;
  display_data[1] = (uint8_t)(disp_volt[2]) - 0x30;
  return;
}



void Current_ADCReading()
{
  int temp_adc_value = 0x00;
  uint8_t input_pin = (value_state) ? PIN_PA7 : PIN_PA6; //False(default) = 3.3V, True = 5V
  
  analogReference(EXTERNAL);
  analogReadResolution(12);
  analogSampleDuration(10);
  delay(1);
  
  for (int i = 0x00; i < 0xFF; i++)
  {
    temp_adc_value = analogRead(input_pin);
    current = current + (temp_adc_value * (2.08333333/4096));
  }
  current = current/(256);
  
  disp_amp = String(current, 4);
  display_data[2] = (uint8_t)(disp_amp[0]) - 0x30;
  display_data[3] = (uint8_t)(disp_amp[2]) - 0x30;
  display_data[4] = (uint8_t)(disp_amp[3]) - 0x30;
  return;
}


//legacy code
/*
void Voltage_ADCInitialize()
{
  //
  //Calibrate offset
  ADC0.CTRLA = 0x21; // Not run in standby sleep mode, low latency EN, ADC EN
  ADC0.CTRLB = 0x00; // Lowest prescale (div 2)
  ADC0.CTRLC = 0x07; // Internal 4.096V reference
  ADC0.CTRLE = 0x0; // 
  ADC0.CTRLF = 0x00;
  ADC0.CTRLD = 0x00; // Disable window comparator
  ADC0.INTCTRL = 0x01; // EN result ready interrupt
  ADC0.MUXPOS = 0x30; // NO PGA, Internal GND Connection
  delay(1);
  analogReference(INTERNAL4V096); //Requires VDD > 4.596V
  analogReadResolution(10);
  analogSampleDuration(6);
  return;
}

void Current_ADCInitialize()
{
  return;
}
*/

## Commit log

2022-10-04 Added Rev1.1 display board and Rev1.4 main board KiCad projects
    [display.kicad_pcb, display.kicad_sch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]
2022-10-05 Added front and back panel enclosure stp and drawing files
    [back_face_plate v17.step, front_face_plate v22.step]
2023-01-03 Added initial code base, improved and fixed hardware up to Rev 1.5/1.2 for the main and display boards respectively, and add pictures of (mostly) complete result
    [INA180 Current Sense Amp.xlsx, display.kicad_pcb, display.kicad_sch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]
